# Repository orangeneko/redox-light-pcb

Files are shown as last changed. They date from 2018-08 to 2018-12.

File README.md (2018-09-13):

## About
Eagle version of PCB for [Redox keyboard](https://github.com/mattdibi/redox-keyboard) with RBG backlight (of each keys).

## PCB
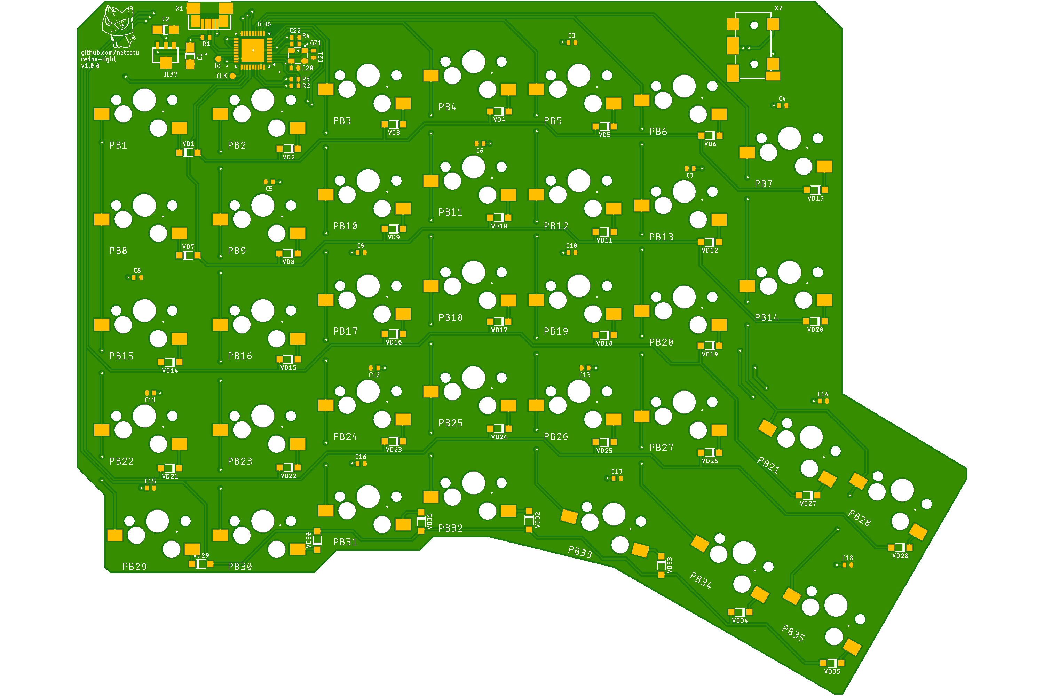
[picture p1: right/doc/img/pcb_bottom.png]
right
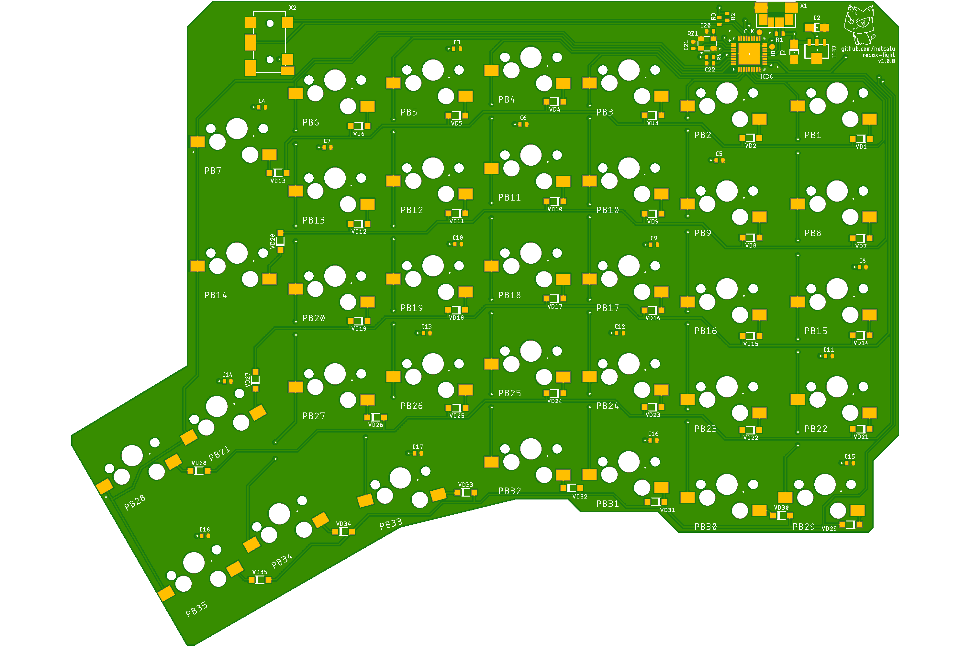
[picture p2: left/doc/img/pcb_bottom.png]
left


## Hardware
* Cortex M3 STM32F103T8U
* SK6812 CMD 3535 Leds (similar with WS2812B)
* Cherry MX switches
* Kailh PCB sockets

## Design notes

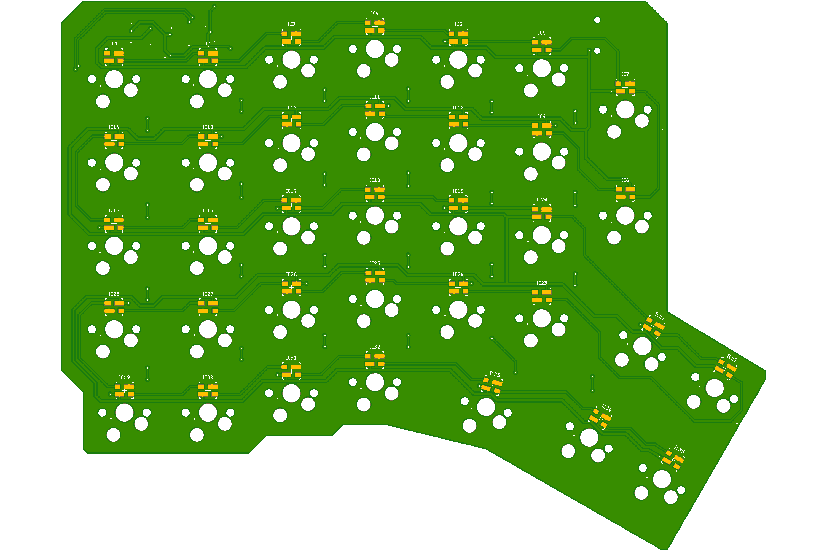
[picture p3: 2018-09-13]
left/doc/img/pcb_top.png

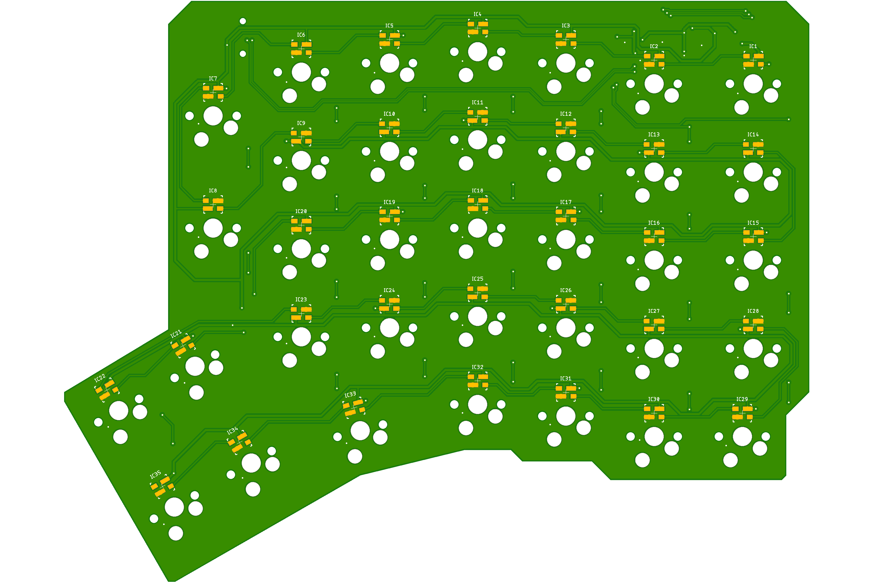
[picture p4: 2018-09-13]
right/doc/img/pcb_top.png

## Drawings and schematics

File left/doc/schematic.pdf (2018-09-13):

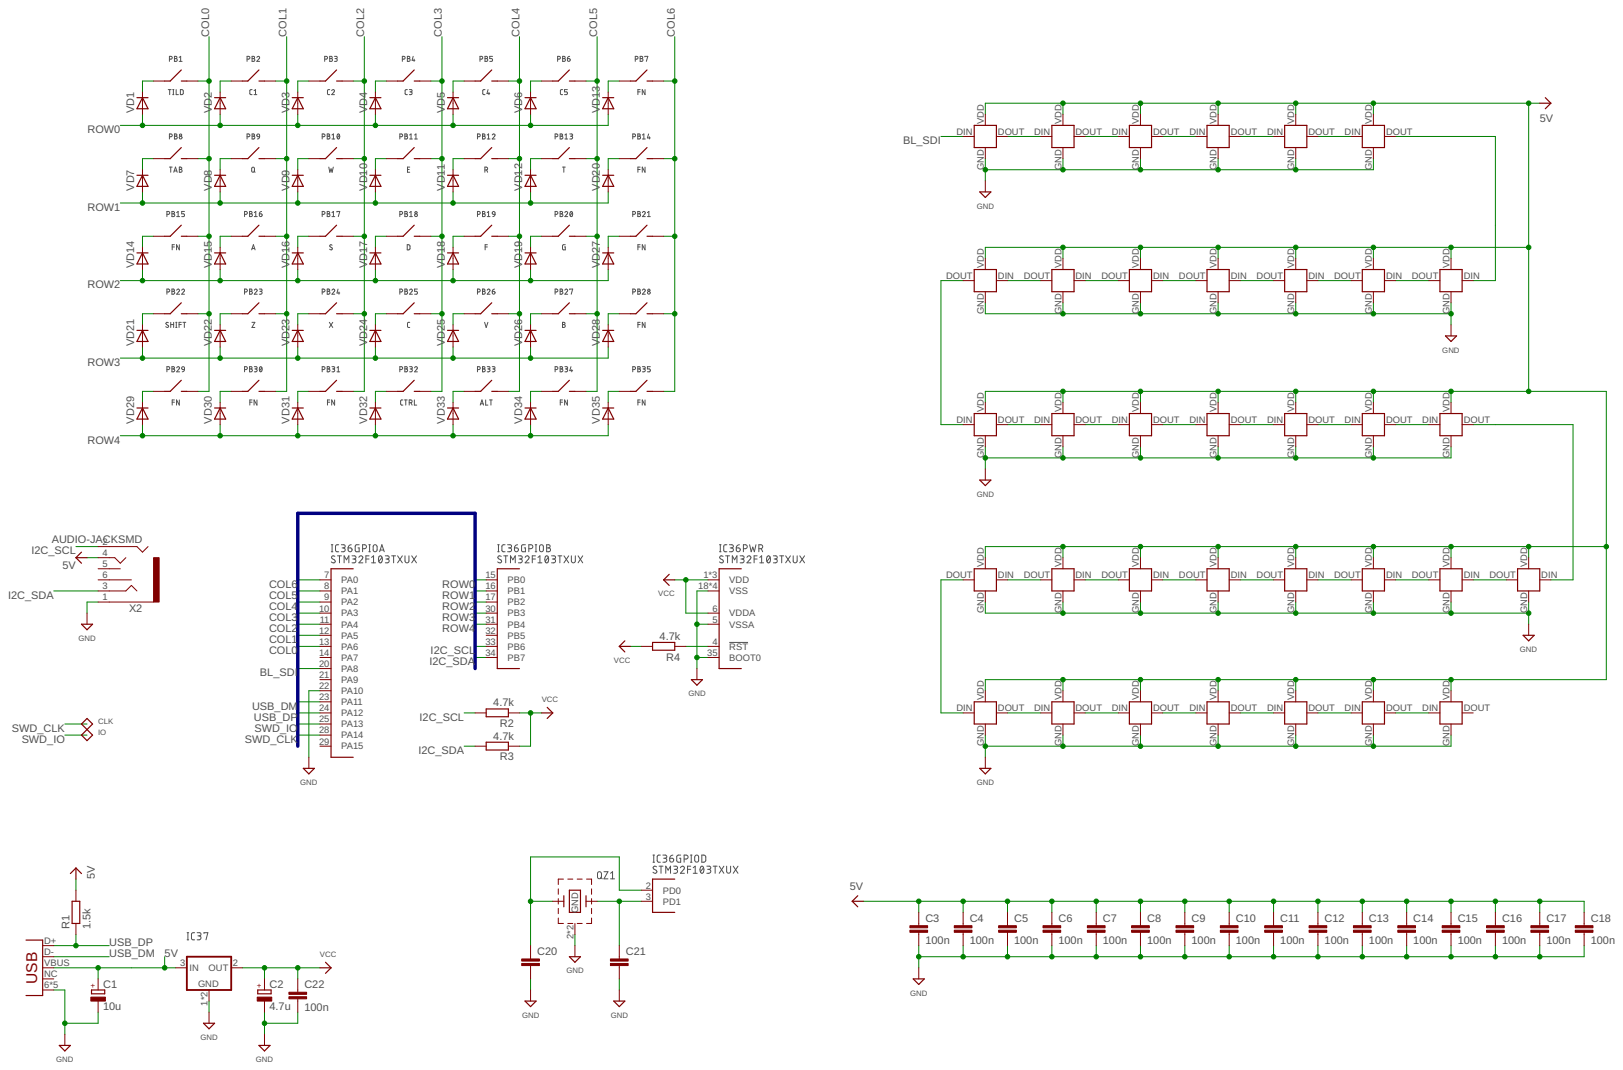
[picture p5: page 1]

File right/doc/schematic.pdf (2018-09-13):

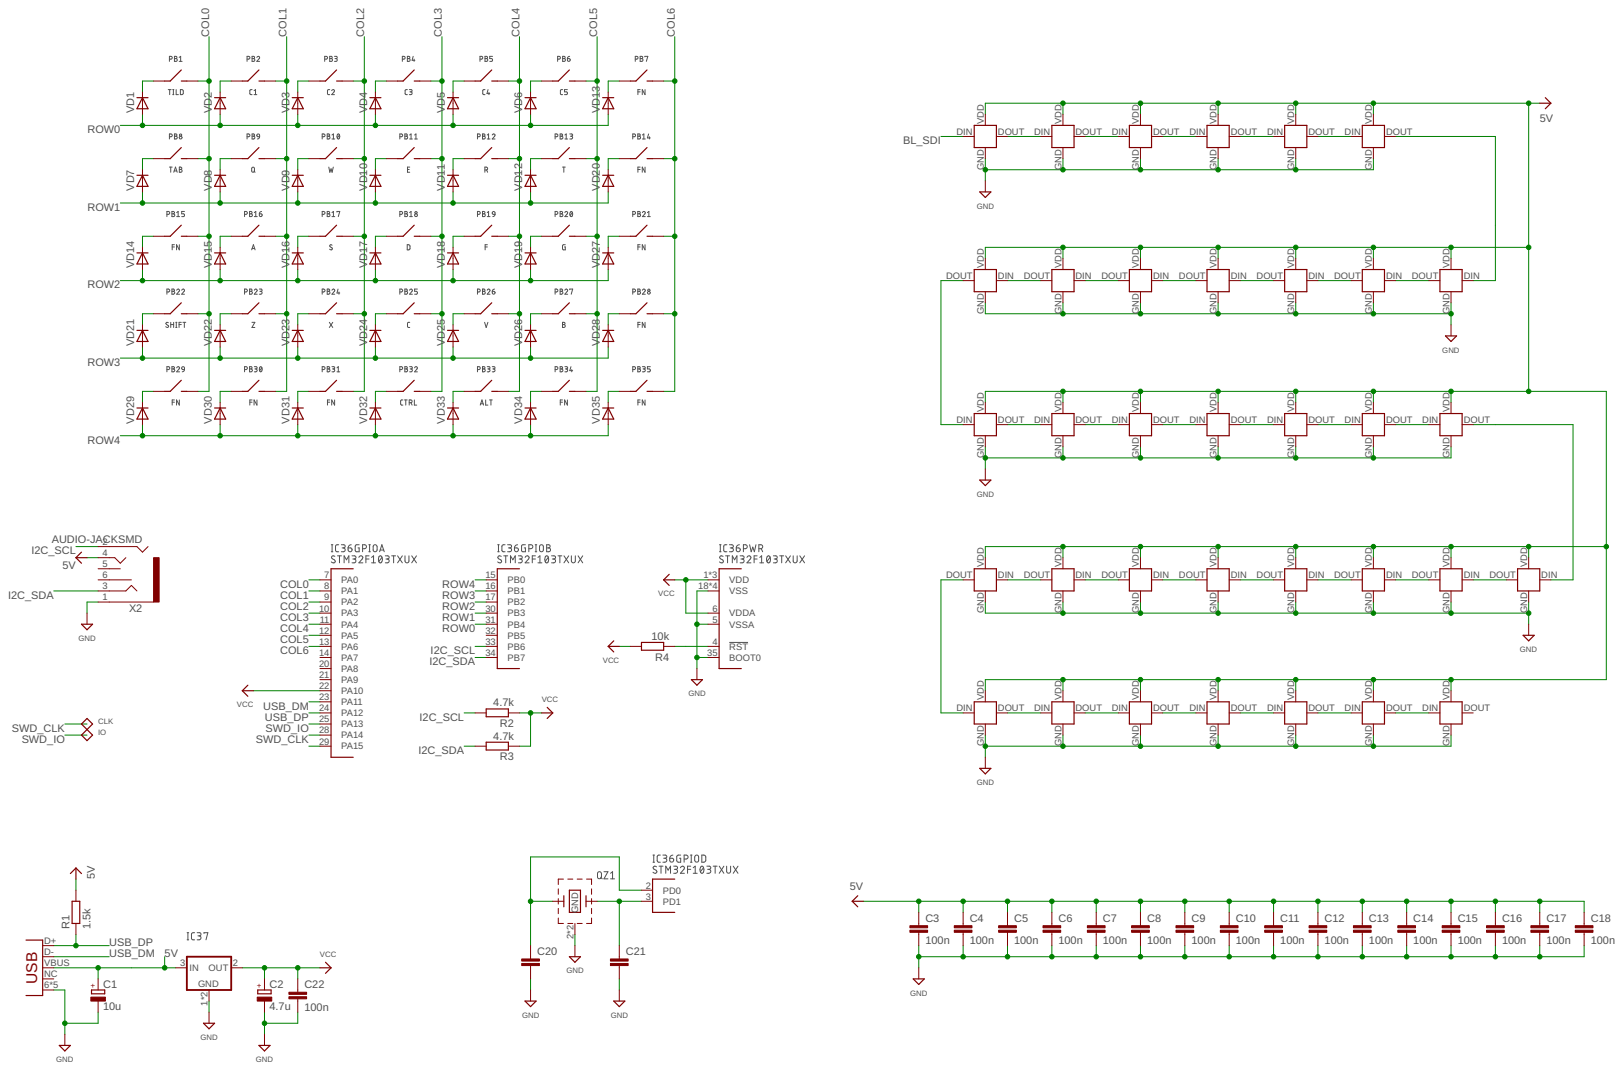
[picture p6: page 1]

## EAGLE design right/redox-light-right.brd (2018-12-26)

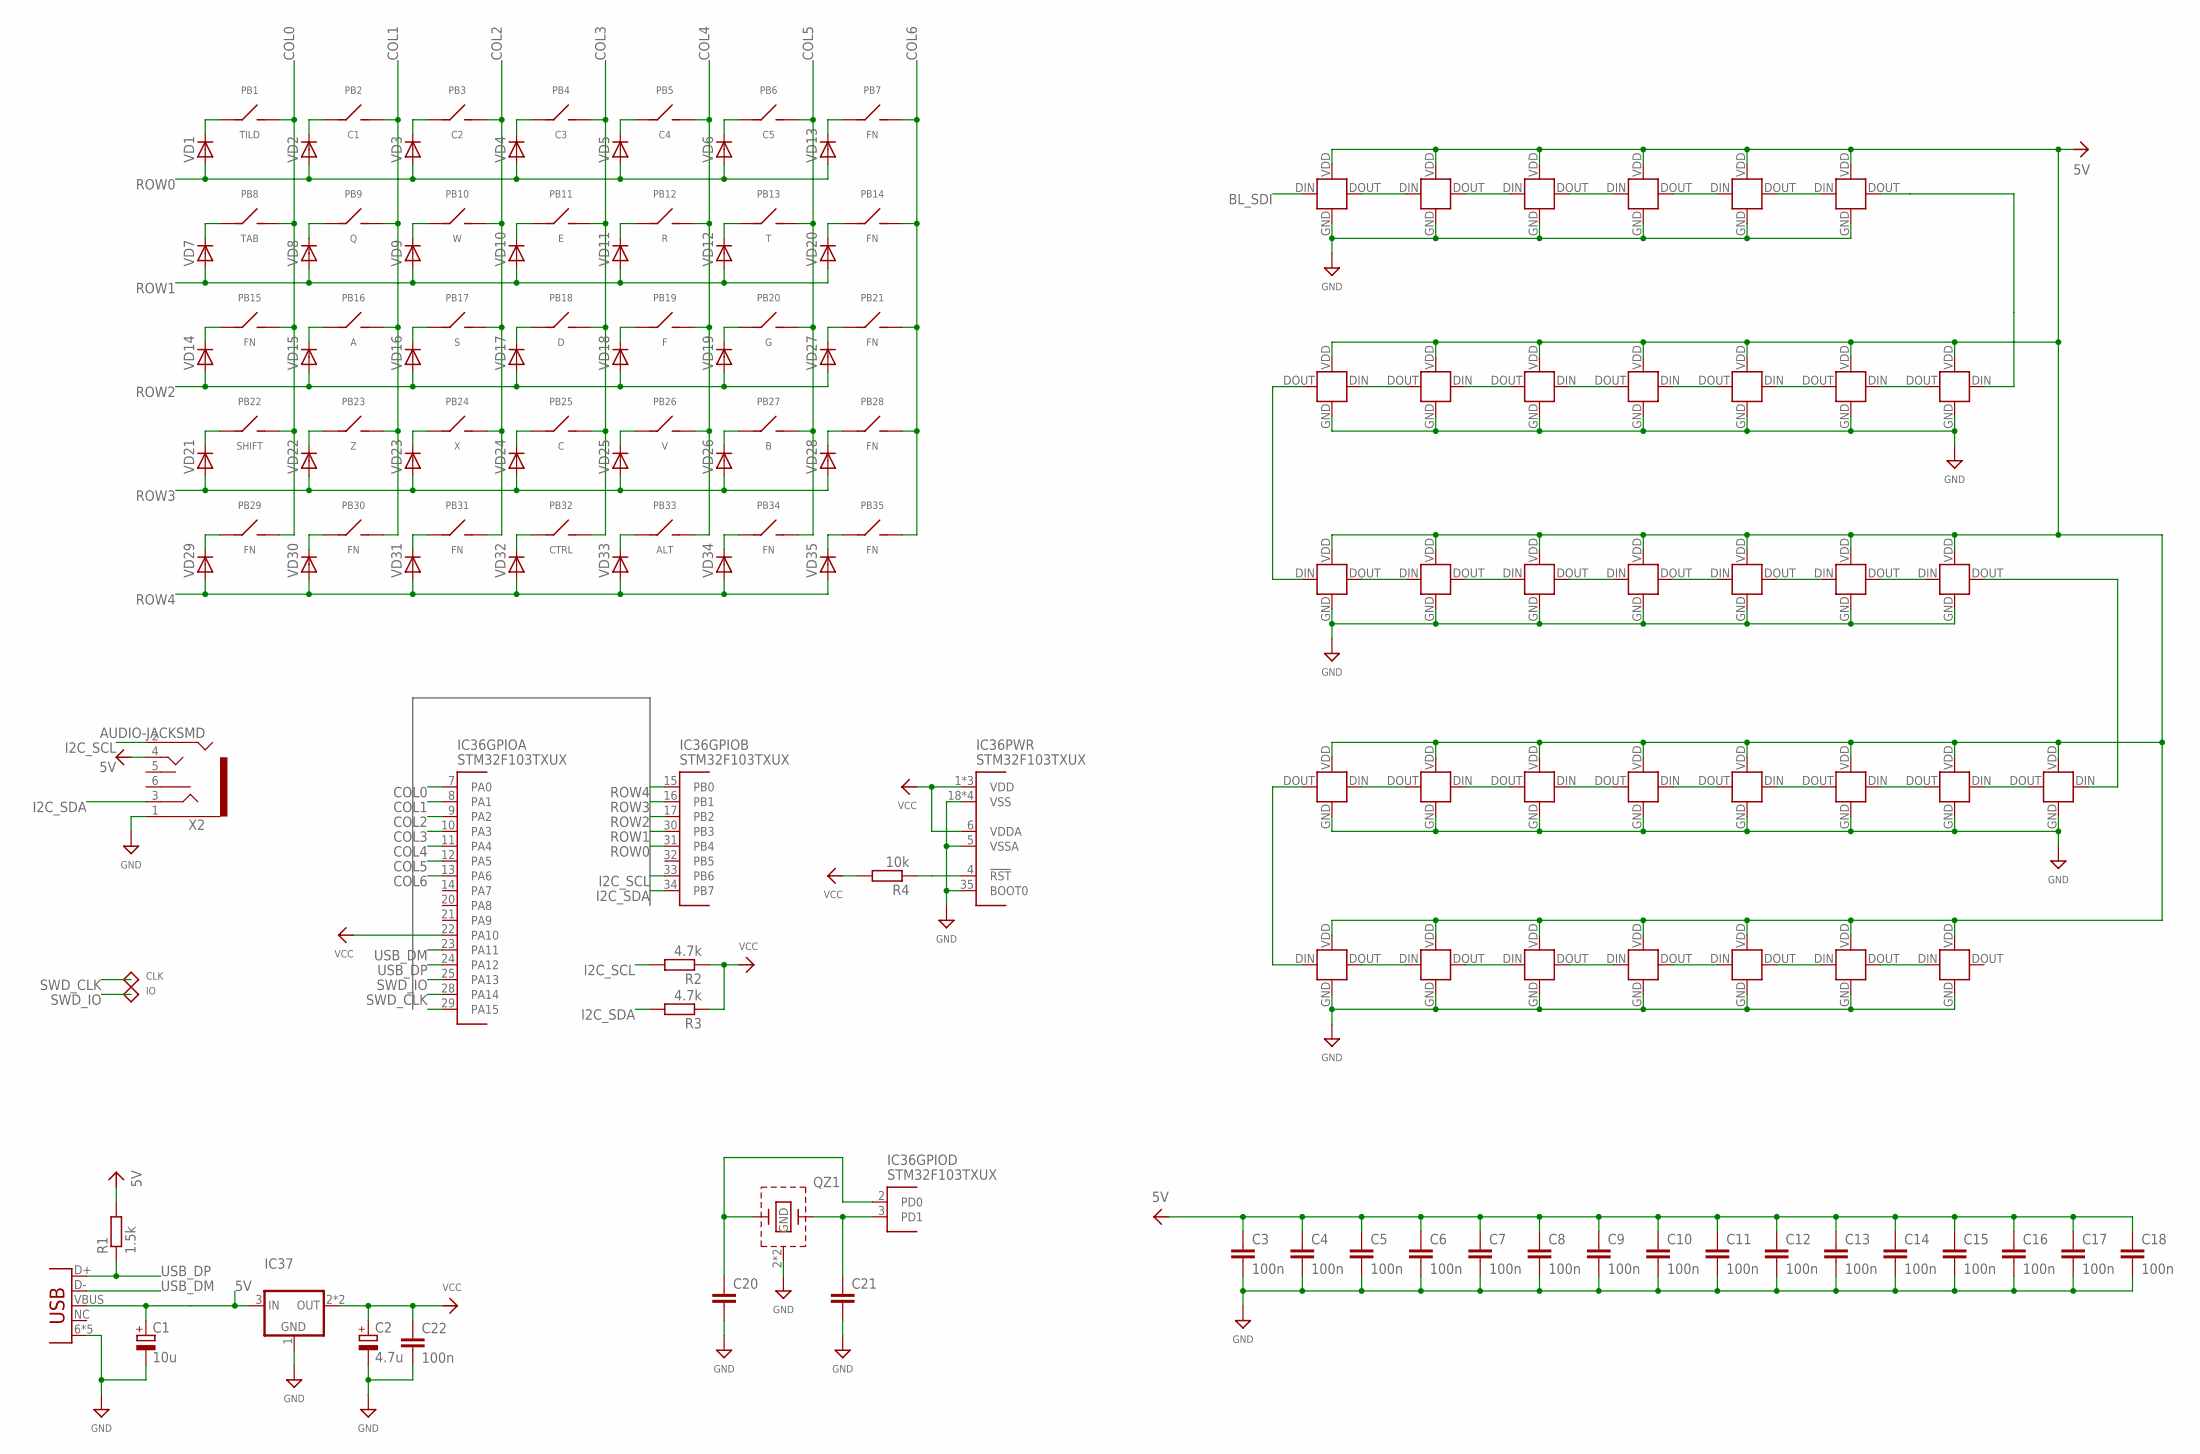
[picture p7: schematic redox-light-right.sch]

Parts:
C1: 10u; SMC_A
C2: 4.7u; SMC_A
C3, C4, C5, C6, C7, C8, C9, C10, C11, C12, C13, C14, C15, C16, C17, C18, C22: 100n; R0402
C20, C21: CAP0402; R0402
IC1, IC2, IC3, IC4, IC5, IC6, IC7, IC8, IC9, IC10, IC11, IC12, IC13, IC14, IC15, IC16, IC17, IC18, IC19, IC20, IC21, IC22, IC23, IC24, IC25, IC26, IC27, IC28, IC29, IC30, IC31, IC32, IC33, IC34, IC35: SK68XX-MINI
IC36: STM32F103TXUX; QFN-36
IC37: LM1117; SOT89
PB1: TILD; CHERRY-MX-KAILH
PB2: C1; CHERRY-MX-KAILH
PB3: C2; CHERRY-MX-KAILH
PB4: C3; CHERRY-MX-KAILH
PB5: C4; CHERRY-MX-KAILH
PB6: C5; CHERRY-MX-KAILH
PB7, PB14, PB15, PB21, PB28, PB29, PB30, PB31, PB34, PB35: FN; CHERRY-MX-KAILH
PB8: TAB; CHERRY-MX-KAILH
PB9: Q; CHERRY-MX-KAILH
PB10: W; CHERRY-MX-KAILH
PB11: E; CHERRY-MX-KAILH
PB12: R; CHERRY-MX-KAILH
PB13: T; CHERRY-MX-KAILH
PB16: A; CHERRY-MX-KAILH
PB17: S; CHERRY-MX-KAILH
PB18: D; CHERRY-MX-KAILH
PB19: F; CHERRY-MX-KAILH
PB20: G; CHERRY-MX-KAILH
PB22: SHIFT; CHERRY-MX-KAILH
PB23: Z; CHERRY-MX-KAILH
PB24: X; CHERRY-MX-KAILH
PB25: C; CHERRY-MX-KAILH
PB26: V; CHERRY-MX-KAILH
PB27: B; CHERRY-MX-KAILH
PB32: CTRL; CHERRY-MX-KAILH
PB33: ALT; CHERRY-MX-KAILH
QZ1: QUARTZ_GND3225; 3225
R1: 1.5k; R0402
R2, R3: 4.7k; R0402
R4: 10k; R0402
TP1: CLK; TP10R
TP2: IO; TP10R
VD1, VD2, VD3, VD4, VD5, VD6, VD7, VD8, VD9, VD10, VD11, VD12, VD13, VD14, VD15, VD16, VD17, VD18, VD19, VD20, VD21, VD22, VD23, VD24, VD25, VD26, VD27, VD28, VD29, VD30, VD31, VD32, VD33, VD34, VD35: DIODE-SOD123; SOD123
X1: USBMICRO_B; USB_MICROB
X2: AUDIO-JACKSMD; PJ-342

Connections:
5V: C1.+, C3.1, C4.1, C5.1, C6.1, C7.1, C8.1, C9.1, C10.1, C11.1, C12.1, C13.1, C14.1, C15.1, C16.1, C17.1, C18.1, IC1.VDD (VCC), IC2.VDD (VCC), IC3.VDD (VCC), IC4.VDD (VCC), IC5.VDD (VCC), IC6.VDD (VCC), IC7.VDD (VCC), IC8.VDD (VCC), IC9.VDD (VCC), IC10.VDD (VCC), IC11.VDD (VCC), IC12.VDD (VCC), IC13.VDD (VCC), IC14.VDD (VCC), IC15.VDD (VCC), IC16.VDD (VCC), IC17.VDD (VCC), IC18.VDD (VCC), IC19.VDD (VCC), IC20.VDD (VCC), IC21.VDD (VCC), IC22.VDD (VCC), IC23.VDD (VCC), IC24.VDD (VCC), IC25.VDD (VCC), IC26.VDD (VCC), IC27.VDD (VCC), IC28.VDD (VCC), IC29.VDD (VCC), IC30.VDD (VCC), IC31.VDD (VCC), IC32.VDD (VCC), IC33.VDD (VCC), IC34.VDD (VCC), IC35.VDD (VCC), IC37.3 (IN), R1.2, X1.VBUS, X2.4
BL_SDI: IC1.DIN, IC36.29 (PA15)
COL0: IC36.7 (PA0), PB1.2, PB8.2, PB15.2, PB22.2, PB29.2
COL1: IC36.8 (PA1), PB2.2, PB9.2, PB16.2, PB23.2, PB30.2
COL2: IC36.9 (PA2), PB3.2, PB10.2, PB17.2, PB24.2, PB31.2
COL3: IC36.10 (PA3), PB4.2, PB11.2, PB18.2, PB25.2, PB32.2
COL4: IC36.11 (PA4), PB5.2, PB12.2, PB19.2, PB26.2, PB33.2
COL5: IC36.12 (PA5), PB6.2, PB13.2, PB20.2, PB27.2, PB34.2
COL6: IC36.13 (PA6), PB7.2, PB14.2, PB21.2, PB28.2, PB35.2
GND: C1.-, C2.-, C3.2, C4.2, C5.2, C6.2, C7.2, C8.2, C9.2, C10.2, C11.2, C12.2, C13.2, C14.2, C15.2, C16.2, C17.2, C18.2, C20.2, C21.2, C22.2, IC1.GND, IC2.GND, IC3.GND, IC4.GND, IC5.GND, IC6.GND, IC7.GND, IC8.GND, IC9.GND, IC10.GND, IC11.GND, IC12.GND, IC13.GND, IC14.GND, IC15.GND, IC16.GND, IC17.GND, IC18.GND, IC19.GND, IC20.GND, IC21.GND, IC22.GND, IC23.GND, IC24.GND, IC25.GND, IC26.GND, IC27.GND, IC28.GND, IC29.GND, IC30.GND, IC31.GND, IC32.GND, IC33.GND, IC34.GND, IC35.GND, IC36.5 (VSSA), IC36.18 (VSS), IC36.26 (VSS), IC36.35 (BOOT0), IC36.36 (VSS), IC36.PGND (VSS), IC37.1 (GND), QZ1.2 (GND), QZ1.4 (GND), X1.6 (GND), X1.7 (GND), X1.8 (GND), X1.9 (GND), X1.GND, X2.1
I2C_SCL: IC36.33 (PB6), R2.2, X2.2
I2C_SDA: IC36.34 (PB7), R3.2, X2.3
unnamed: IC1.DOUT, IC2.DIN
unnamed: IC2.DOUT, IC3.DIN
unnamed: IC3.DOUT, IC4.DIN
unnamed: IC4.DOUT, IC5.DIN
unnamed: IC5.DOUT, IC6.DIN
unnamed: IC7.DOUT, IC8.DIN
unnamed: PB1.1, VD1.C
unnamed: IC21.DOUT, IC22.DIN
unnamed: IC22.DOUT, IC23.DIN
unnamed: IC23.DOUT, IC24.DIN
unnamed: IC24.DOUT, IC25.DIN
unnamed: IC25.DOUT, IC26.DIN
unnamed: IC8.DOUT, IC9.DIN
unnamed: IC13.DOUT, IC14.DIN
unnamed: IC26.DOUT, IC27.DIN
unnamed: IC20.DOUT, IC21.DIN
unnamed: PB4.1, VD4.C
unnamed: PB3.1, VD3.C
unnamed: PB5.1, VD5.C
unnamed: PB6.1, VD6.C
unnamed: PB2.1, VD2.C
unnamed: PB7.1, VD13.C
unnamed: C20.1, IC36.2 (PD0), QZ1.3 (2)
unnamed: PB8.1, VD7.C
unnamed: PB9.1, VD8.C
unnamed: PB10.1, VD9.C
unnamed: PB11.1, VD10.C
unnamed: PB12.1, VD11.C
unnamed: PB13.1, VD12.C
unnamed: PB14.1, VD20.C
unnamed: C21.1, IC36.3 (PD1), QZ1.1
unnamed: IC9.DOUT, IC10.DIN
unnamed: IC10.DOUT, IC11.DIN
unnamed: IC11.DOUT, IC12.DIN
unnamed: IC36.4 (!RST), R4.1
unnamed: IC12.DOUT, IC13.DIN
unnamed: IC6.DOUT, IC7.DIN
unnamed: IC14.DOUT, IC15.DIN
unnamed: IC15.DOUT, IC16.DIN
unnamed: IC16.DOUT, IC17.DIN
unnamed: IC17.DOUT, IC18.DIN
unnamed: IC18.DOUT, IC19.DIN
unnamed: IC19.DOUT, IC20.DIN
unnamed: PB15.1, VD14.C
unnamed: PB16.1, VD15.C
unnamed: PB17.1, VD16.C
unnamed: PB18.1, VD17.C
unnamed: PB19.1, VD18.C
unnamed: PB20.1, VD19.C
unnamed: IC27.DOUT, IC28.DIN
unnamed: IC29.DOUT, IC30.DIN
unnamed: PB22.1, VD21.C
unnamed: PB23.1, VD22.C
unnamed: PB29.1, VD29.C
unnamed: PB30.1, VD30.C
unnamed: PB24.1, VD23.C
unnamed: PB25.1, VD24.C
unnamed: PB26.1, VD25.C
unnamed: PB27.1, VD26.C
unnamed: PB21.1, VD27.C
unnamed: PB28.1, VD28.C
unnamed: PB31.1, VD31.C
unnamed: PB32.1, VD32.C
unnamed: PB33.1, VD33.C
unnamed: PB34.1, VD34.C
unnamed: PB35.1, VD35.C
unnamed: IC30.DOUT, IC31.DIN
unnamed: IC31.DOUT, IC32.DIN
unnamed: IC32.DOUT, IC33.DIN
unnamed: IC33.DOUT, IC34.DIN
unnamed: IC34.DOUT, IC35.DIN
unnamed: IC28.DOUT, IC29.DIN
ROW0: IC36.31 (PB4), VD1.A, VD2.A, VD3.A, VD4.A, VD5.A, VD6.A, VD13.A
ROW1: IC36.30 (PB3), VD7.A, VD8.A, VD9.A, VD10.A, VD11.A, VD12.A, VD20.A
ROW2: IC36.17 (PB2), VD14.A, VD15.A, VD16.A, VD17.A, VD18.A, VD19.A, VD27.A
ROW3: IC36.16 (PB1), VD21.A, VD22.A, VD23.A, VD24.A, VD25.A, VD26.A, VD28.A
ROW4: IC36.15 (PB0), VD29.A, VD30.A, VD31.A, VD32.A, VD33.A, VD34.A, VD35.A
SWD_CLK: IC36.28 (PA14), TP1.TP
SWD_IO: IC36.25 (PA13), TP2.TP
USB_DM: IC36.23 (PA11), X1.D-
USB_DP: IC36.24 (PA12), R1.1, X1.D+
VCC: C2.+, C22.1, IC36.1 (VDD), IC36.6 (VDDA), IC36.19 (VDD), IC36.22 (PA10), IC36.27 (VDD), IC37.2 (OUT), IC37.4 (OUT), R2.1, R3.1, R4.2

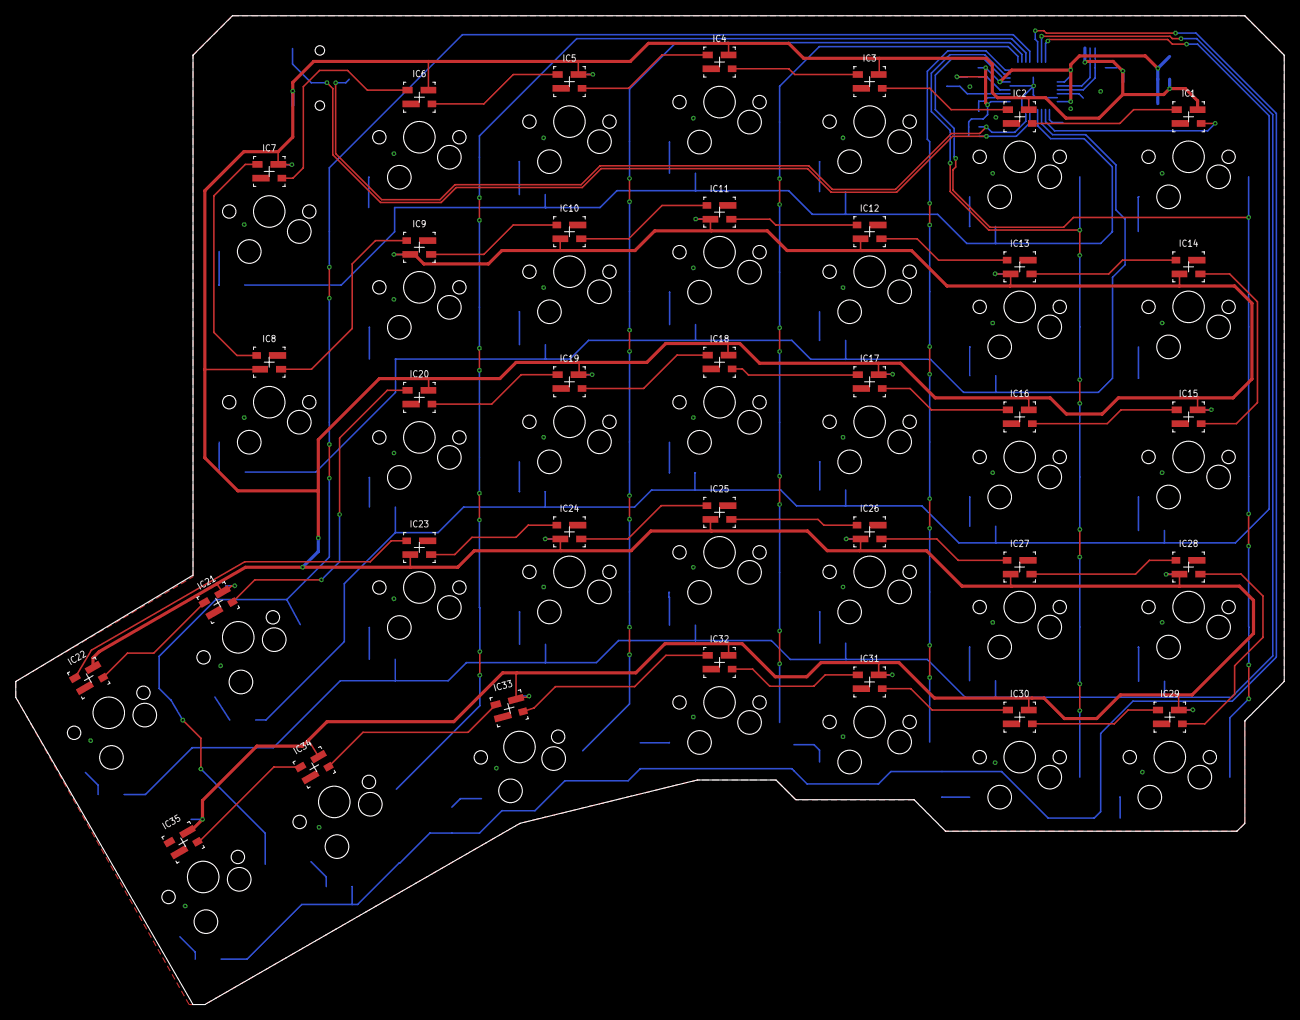
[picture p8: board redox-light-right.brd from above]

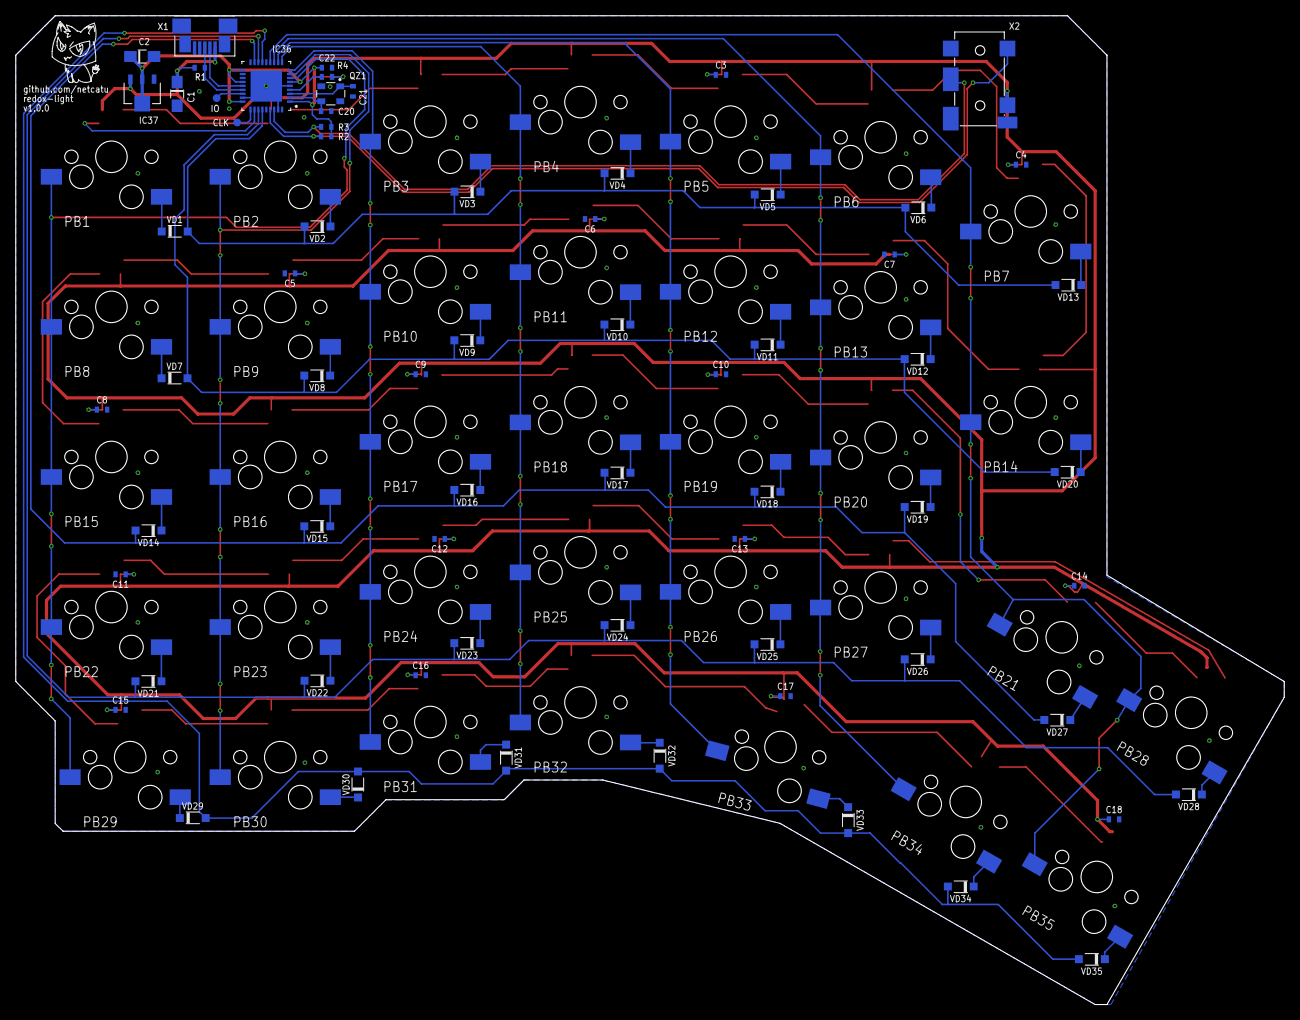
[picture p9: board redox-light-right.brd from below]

Board: 2 copper layers, 161.0 x 125.5 mm, 138 parts (68 on the bottom side), 94 nets.

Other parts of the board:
U$1: LOGO2

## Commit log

2018-07-30 schematic, board components alignment
    [redox-light.brd, redox-light.sch]
2018-07-31 layout template
    [redox-light.brd, redox-light.sch]
2018-08-21 aligned buttons, board layout completed
    [redox-light.brd, redox-light.sch]
2018-08-23 layout, outline, silk update
    [redox-light.brd, redox-light.sch]
2018-08-23 make schematic more simply, added SWD connector
    [redox-light.brd, redox-light.sch]
2018-08-27 silk layer update
    [redox-light.brd, redox-light.sch]
2018-09-10 replace swd connector with tps, move files
    [redox-light-left.brd, redox-light-left.sch]
2018-09-10 added right part
    [redox-light-right.brd, redox-light-right.sch]
2018-09-10 some improoves
    [redox-light-left.brd, redox-light-left.sch, redox-light-right.brd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]
2018-09-13 drc warn fixes
    [redox-light-left.brd, redox-light-right.brd]
2018-09-13 first release, updated docs, added gerbers
    [copper_bottom.gbr, copper_top.gbr, drills.xln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]
2018-12-26 lm1117 pkg fix
    [redox-light-left.brd, redox-light-left.sch, redox-light-right.brd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]
